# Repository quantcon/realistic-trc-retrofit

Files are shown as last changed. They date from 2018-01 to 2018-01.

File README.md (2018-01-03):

# Realistic CB Radio Retrofit Project
Assets for retrofitting a Realistic TRC-219 with Teensy 3.2

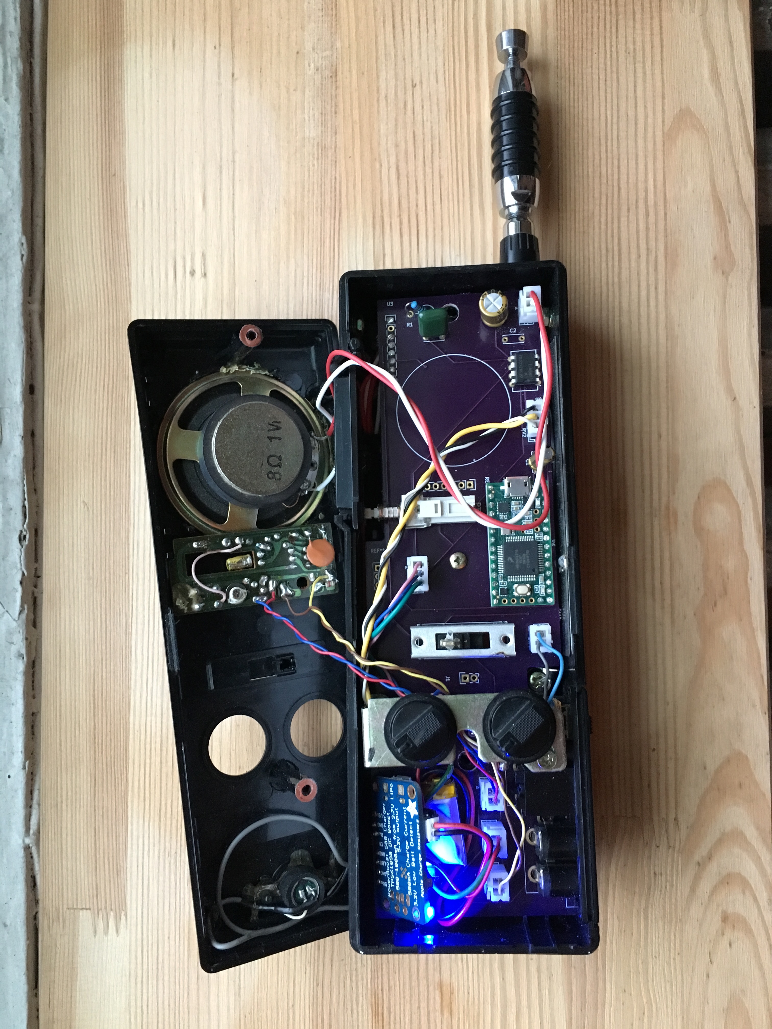
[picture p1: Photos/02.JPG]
Old Realistic radio with Teensy guts The guts


# Required tools:

* KiCad PCB
    * http://kicad-pcb.org/
* Arduino IDE
    * https://www.arduino.cc/en/Main/Software
* Teensy Microcontroller
    * https://www.pjrc.com/store/teensy32.html
* PCB Fabricator
    * https://oshpark.com/ (or similar!)

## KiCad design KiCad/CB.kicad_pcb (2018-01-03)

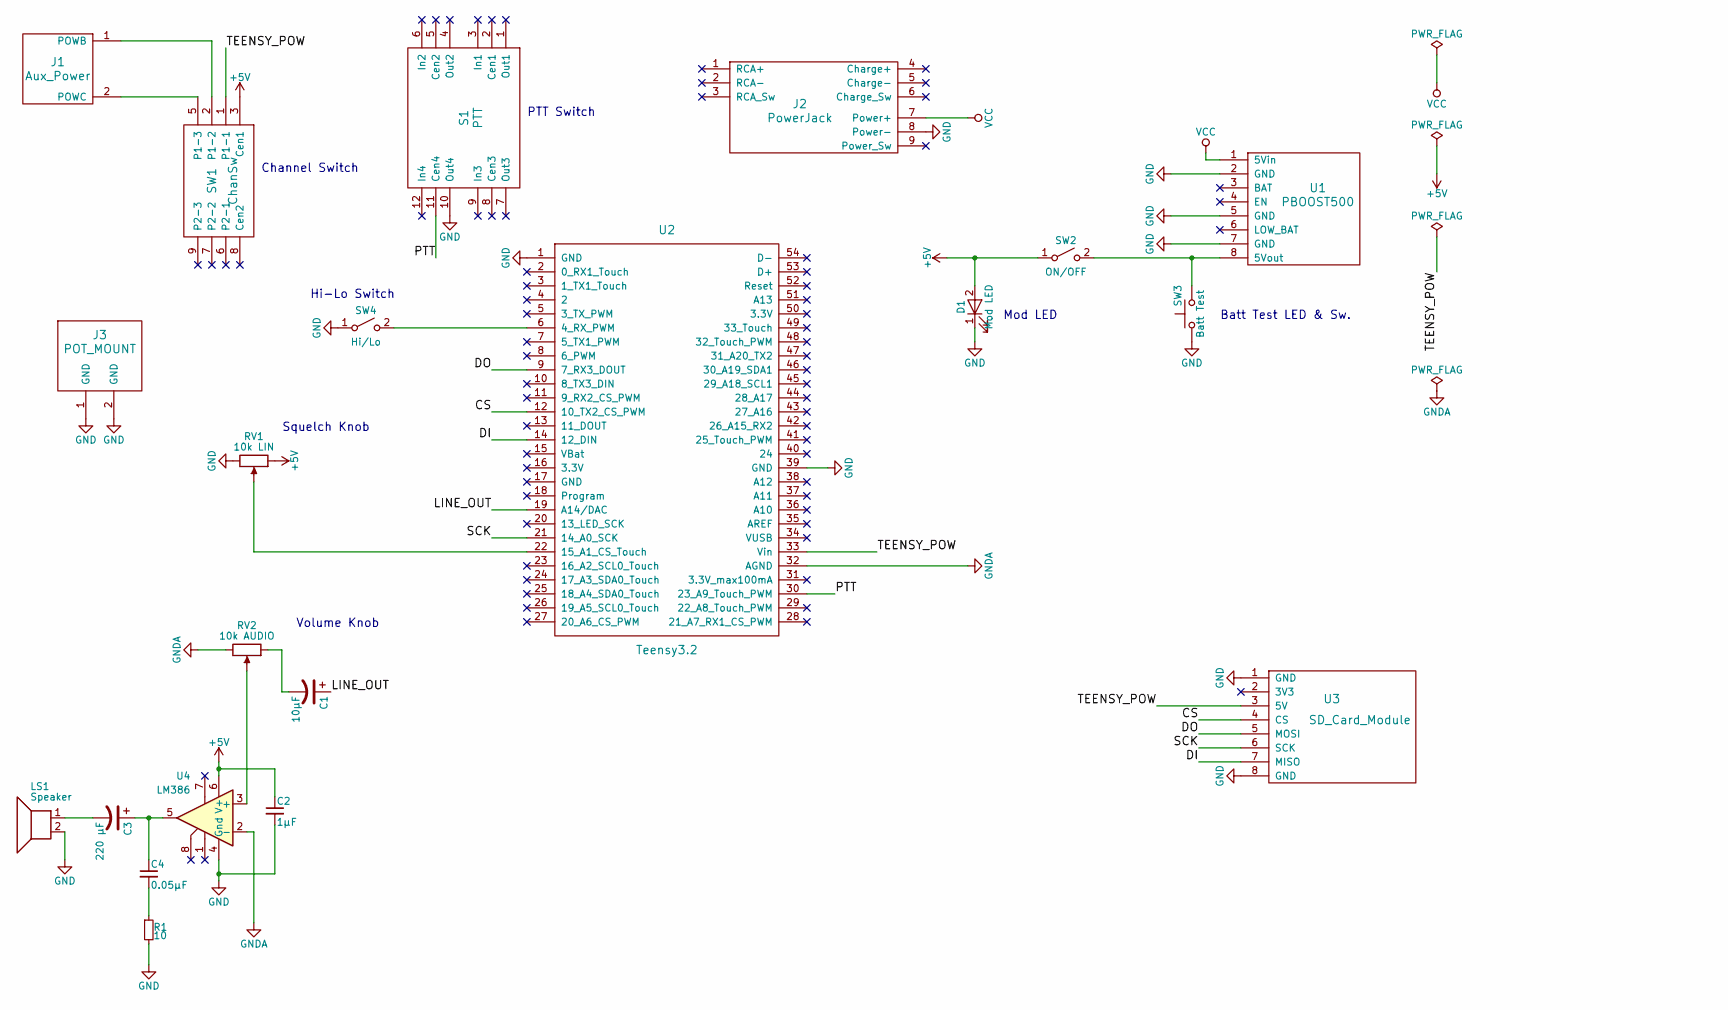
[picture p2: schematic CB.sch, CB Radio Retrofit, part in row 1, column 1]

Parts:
C1: 10µF; C_Disc_D6.0mm_W2.5mm_P5.00mm
C2: 1µF; C_Disc_D6.0mm_W2.5mm_P5.00mm
C3: 220 µF; C_Disc_D6.0mm_W2.5mm_P5.00mm
C4: 0.05µF; C_Disc_D6.0mm_W2.5mm_P5.00mm
D1: Mod LED; JST_EH_B02B-EH-A_02x2.50mm_Straight
J1: Aux_Power; Pin_Header_Straight_1x02
J2: PowerJack; Power_Jack
J3: POT_MOUNT
LS1: Speaker; JST_EH_B02B-EH-A_02x2.50mm_Straight
R1: 10; Resistor_Vertical_RM5mm
RV1: 10k LIN; JST_EH_B03B-EH-A_03x2.50mm_Straight
RV2: 10k AUDIO; JST_EH_B03B-EH-A_03x2.50mm_Straight
S1: PTT; 4pdt
SW1: ChanSw; 3pdt
SW2: ON/OFF; JST_EH_B02B-EH-A_02x2.50mm_Straight
SW3: Batt Test; JST_EH_B02B-EH-A_02x2.50mm_Straight
SW4: Hi/Lo; JST_EH_B02B-EH-A_02x2.50mm_Straight
U1: PBOOST500; Pin_Header_Straight_1x08
U2: Teensy3.2; Teensy30_31_32_LC
U3: SD_Card_Module; Pin_Header_Straight_1x08
U4: LM386; DIP-8_W7.62mm

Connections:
+5V: C2.1, D1.2 (A), RV1.1, SW1.3 (Cen1), SW2.1 (A), U4.6 (V+)
/CS: U2.12 (10_TX2_CS_PWM), U3.4 (CS)
/DI: U2.14 (12_DIN), U3.7 (MISO)
/DO: U2.9 (7_RX3_DOUT), U3.5 (MOSI)
/LINE_OUT: C1.1, U2.19 (A14/DAC)
/PTT: S1.11 (Cen4), U2.30 (23_A9_Touch_PWM)
/SCK: U2.21 (14_A0_SCK), U3.6 (SCK)
/TEENSY_POW: SW1.1 (P1-1), U2.33 (Vin), U3.3 (5V)
GND: C2.2, D1.1 (K), J2.8 (Power-), J3.1, J3.2, LS1.2, R1.2, RV1.3, S1.10 (Out4), SW3.1, SW4.1 (A), U1.2 (GND), U1.5 (GND), U1.7 (GND), U2.1 (GND), U2.39 (GND), U3.1 (GND), U3.8 (GND), U4.4 (Gnd)
GNDA: RV2.3, U2.32 (AGND), U4.2 (-)
unnamed: C1.2, RV2.1
unnamed: C3.1, C4.1, U4.5
unnamed: C3.2, LS1.1
unnamed: C4.2, R1.1
unnamed: J1.1 (POWB), SW1.2 (P1-2)
unnamed: J1.2 (POWC), SW1.5 (P1-3)
unnamed: RV1.2, U2.22 (15_A1_CS_Touch)
unnamed: RV2.2, U4.3 (+)
unnamed: SW2.2 (B), SW3.2, U1.8 (5Vout)
unnamed: SW4.2 (B), U2.6 (4_RX_PWM)
VCC: J2.7 (Power+), U1.1 (5Vin)

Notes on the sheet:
PTT Switch
Channel Switch
Volume Knob
Squelch Knob
Batt Test LED & Sw.
Mod LED
Hi-Lo Switch

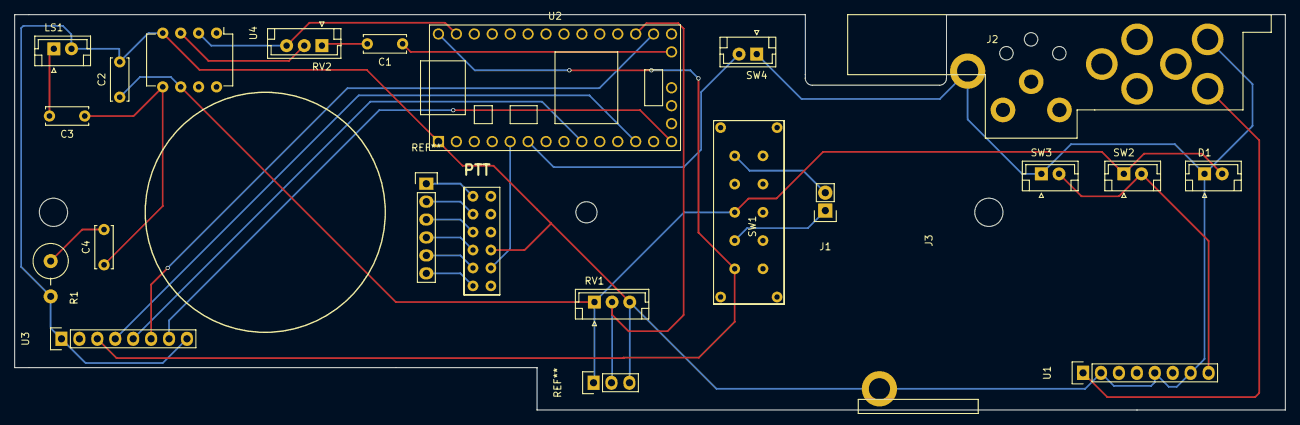
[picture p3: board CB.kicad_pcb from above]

Board: 2 copper layers, 180.0 x 56.0 mm, 21 parts (0 on the bottom side), 21 nets.

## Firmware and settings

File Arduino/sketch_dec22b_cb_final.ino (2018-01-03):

#include <Audio.h>
#include <Wire.h>
#include <SPI.h>
#include <SD.h>
#include <Bounce.h>

#include <play_sd_mp3.h>

AudioPlaySdMp3           playMp31;
AudioMixer4              mixer1;
AudioOutputAnalog        dac1;

AudioConnection          patchCord1(playMp31, 0, mixer1, 0);
AudioConnection          patchCord2(mixer1, dac1);

Bounce nextButton = Bounce(3, 150);

String albums[7] = {"A", "B", "C", "D", "E", "F", "G"};
int numberTracks[7] = {36, 39, 9, 15, 21, 18, 24};

int albumKnob = 0;
int currentAlbum = 0;
int currentTrack = 0;

void setup() {
  Serial.begin(9600);
  
  pinMode(3, INPUT_PULLUP);
  
  AudioMemory(25);

  SPI.setMOSI(7);
  SPI.setSCK(14);

  if (!(SD.begin(10))) {
    while (1) {
      Serial.println("Unable to access the SD card");
      delay(500);
    }
  }

  playTrack();
}

void playTrack() {
  char albumName[2];
  albums[currentAlbum].toCharArray(albumName, 2);
  
  char filepath[9];
  sprintf(filepath, "%s/%02d.MP3", albumName, currentTrack + 1);
  
  playMp31.play(filepath);
  Serial.println(filepath);
}

void loop() {
  if (nextButton.update()) {
    if (nextButton.fallingEdge()) {
      nextTrack();
      playTrack();
    }
  } else {
    int albumWas = currentAlbum;
    albumKnob = analogRead(1);
    currentAlbum = albumKnob / 170;
  
    if (albumWas != currentAlbum) {
      currentTrack = 0;
      playTrack();
      delay(1200);
    }
  }

  if (!playMp31.isPlaying()) {
    nextTrack();
    playTrack();
  }
}

void nextTrack() {
  int total = numberTracks[currentAlbum];
  currentTrack = (currentTrack + 1) % total;
}
